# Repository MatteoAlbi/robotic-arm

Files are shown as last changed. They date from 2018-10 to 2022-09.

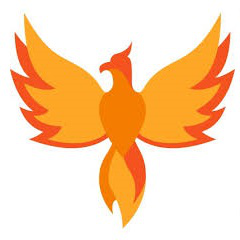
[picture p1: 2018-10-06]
LAST VERSIONS/python, drawing/images/phoenix.jpg

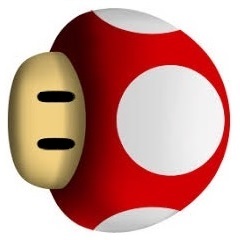
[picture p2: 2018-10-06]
LAST VERSIONS/python, drawing/images/mushroom.jpg

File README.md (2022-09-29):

# robotic-arm
Project developed for the high school graduation final exam.
It's a robotic arm capable to draw simple images or move objects with a claw.

## Description
The robotic arm has been build with ordinary servo-motors and joints designed by myself using SolidWorks and created via 3D-printing (files [here](/solid%20works%20arm%20design)).  
It has two different working configurations:
- **Drawing**: the arm is equipped with a slot for a pancil. An image is processed using a python script, controlled commands are sent via serial communication and executed.
- **Claw**: the arm is controlled via radiocontroller (Turnigy TGY-i6 AFHDS) to move in the 3D space and open/close a claw.

## Python folder
- [braccio](/python/braccio.py): generates a txt file containing the coordinates of the points the arm must follow to draw the image.
- [classes](/python/classes.py): contains basic classes to manage points an lines. It's used in [braccio](/python/braccio.py) to create the drawing steps.
- [comunicazioneArduino_1_0](/python/comunicazioneArduino_1_0.py): manages the communications with the Arduino controlling the servomotors. It reads the file generated by [braccio](/python/braccio.py) and sends the correct commands to the robotic arm.
- [disegna](/python/disegna.py): simulates the drawing process of the robotic arm using the `turtle` library. 
- [dfs](/python/dfs_1_1.py): generates a txt file like [braccio](/python/braccio.py), but implementing a DPS graph visit to compute the drawing steps ([previous version](/python/dfs.py)).
- Code testing: [proveCV_test](/python/proveCV_test.py), [testComunicazioneArduino](/python/testComunicazioneArduino.py), [testBraccio](/python/testBraccio.py).
- Test files: `1.jpg`, `lines.txt`, `prova.jpg`, `prova.txt`.

## Arduino folder
Containing different scripts, e.g. reading the receiver linked to the radiocontroller (e.g. `RX_PCI_MUX`), controlling the robotic arm via python script (`braccio_automatico`), using the calw config. (`braccio_pinza`, `braccio_radiocomandato`), testing scripts used in the development (e.g. `test_pwm_2`, `controllo_vel_motori`, `test_comunicazione_python`).

## LAST VERSIONS folder
Contains the working scripts for each application:
- [arduino, claw](/LAST%20VERSIONS/arduino%2C%20claw): arduino script to control the robotic arm in claw configuration.
- [arduino, drawing](/LAST%20VERSIONS/arduino%2C%20drawing): arduino script that reads and executes commands received on serial port.
- [python, drawing](/LAST%20VERSIONS/python%2C%20drawing): it's devided in two main scripts:
  - [image_analysis](/LAST%20VERSIONS/python%2C%20drawing/image_analysis.py): generates a txt file containing the coordinates of the points the arm must follow to draw the image.  Images examples are saved in the folder [images](/LAST%20VERSIONS/python%2C%20drawing/images) and the image to be analysed is specified in the [config file](/LAST%20VERSIONS/python%2C%20drawing/config.txt). The generated file is saved as `path.txt`.
  - [Arduino_communication](/LAST%20VERSIONS/python%2C%20drawing/Arduino_communication.py): generates and sends the commands to the robotic arm via serial port based on the text file `path.txt`.

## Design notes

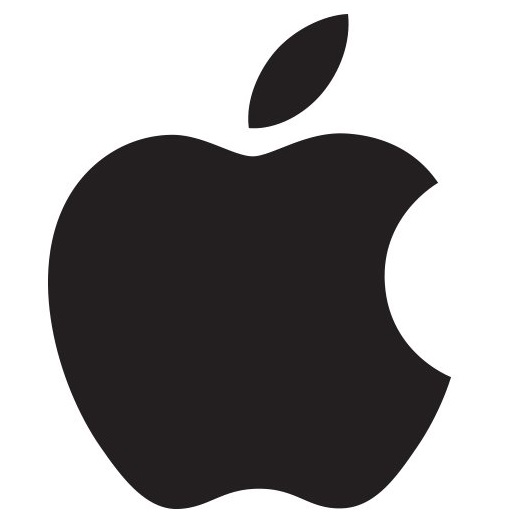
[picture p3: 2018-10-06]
LAST VERSIONS/python, drawing/images/apple.jpg

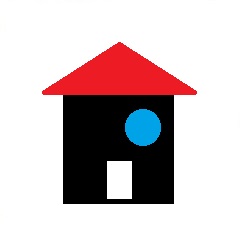
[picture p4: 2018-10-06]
LAST VERSIONS/python, drawing/images/house.jpg

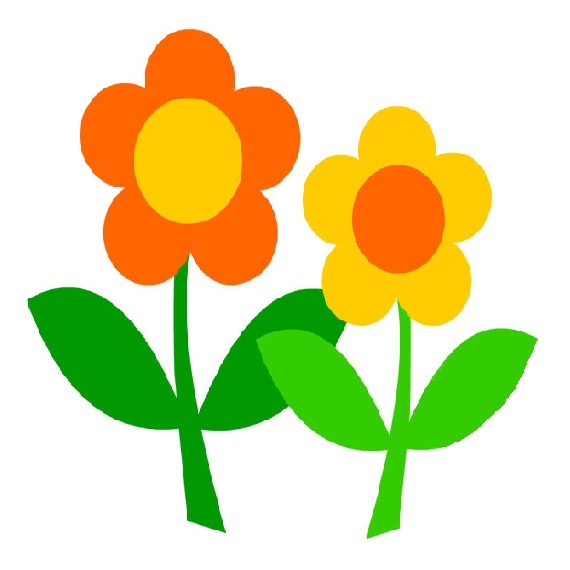
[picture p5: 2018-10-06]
LAST VERSIONS/python, drawing/images/fiore.jpg

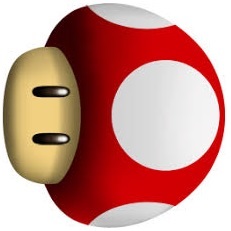
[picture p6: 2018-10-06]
python/prova.jpg

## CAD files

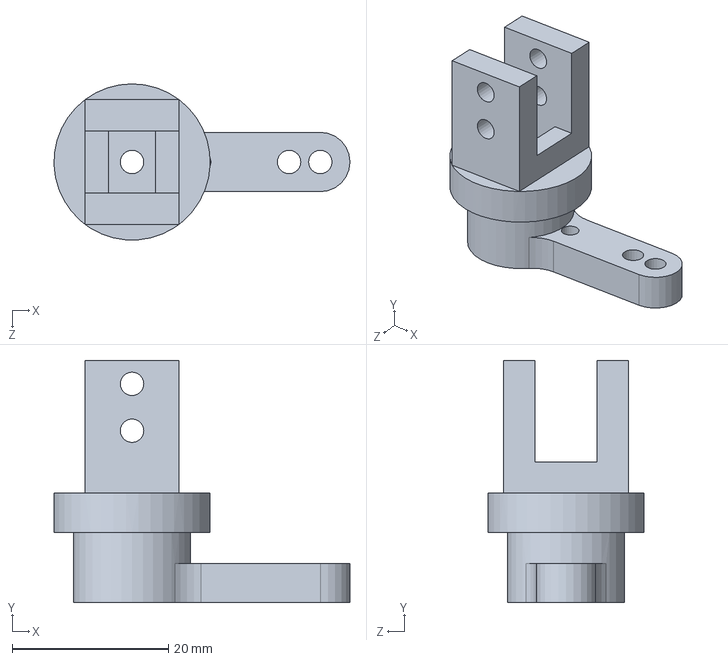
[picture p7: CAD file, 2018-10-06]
solid works arm design/trasmissione verticale.SLDPRT
37.9 x 31.0 x 20.0 mm

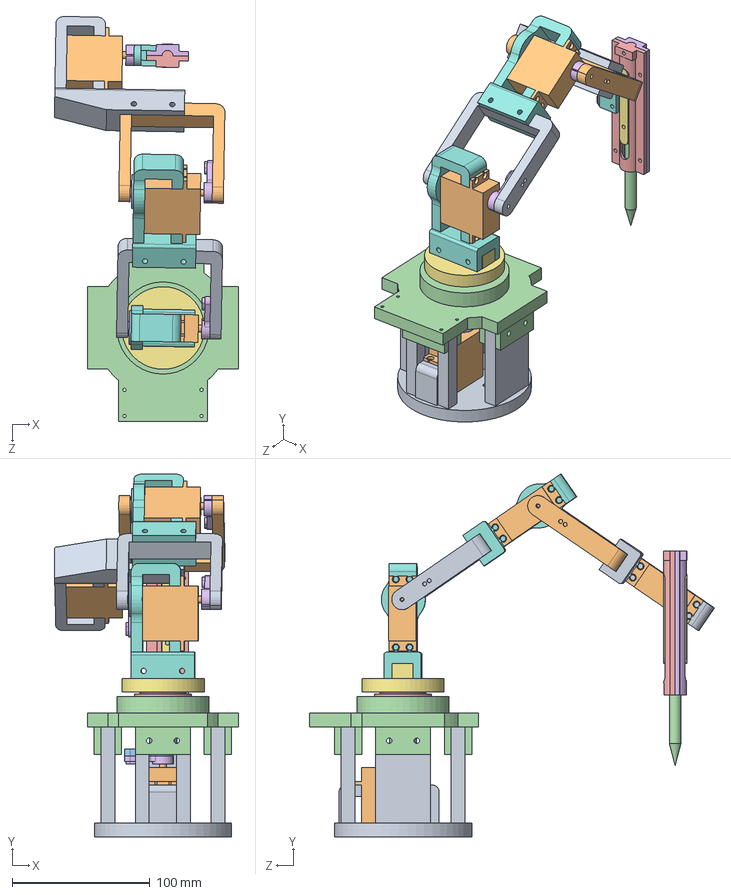
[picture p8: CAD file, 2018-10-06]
solid works arm design/braccio robotico.SLDASM
133.9 x 263.9 x 294.5 mm
base sotto
motore x 4
trasmissione verticale
base sopra
cuscinetto a rulli conici
braccio motore x 4
base motore
attacco x 2
parte rotante
parte rotante penna
cuscinetto a sfera x 2
penna
penna esterno dx
penna esterno sx
penna interno
aggancio penna
attacco penna

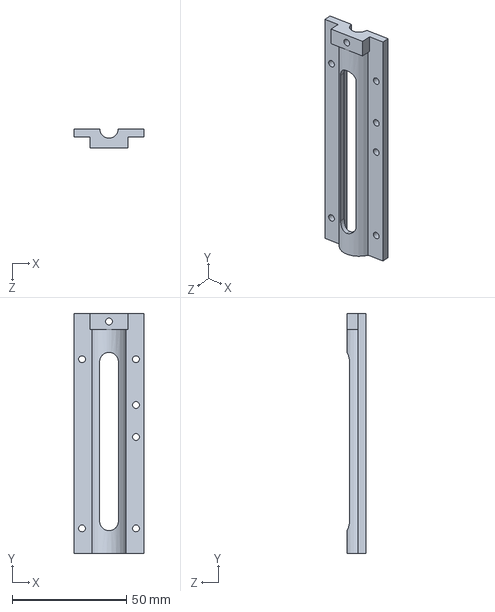
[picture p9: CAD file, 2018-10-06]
solid works arm design/penna esterno sx.SLDPRT
30.6 x 105.0 x 8.30 mm

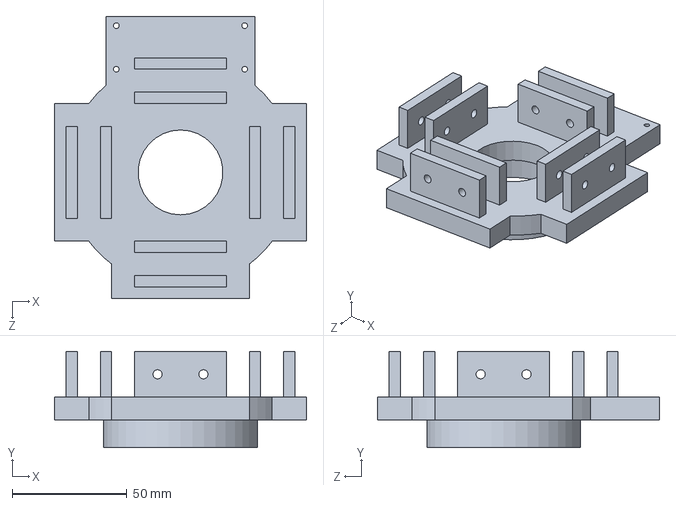
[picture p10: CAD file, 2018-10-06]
solid works arm design/base sopra.SLDPRT
110.0 x 42.0 x 123.0 mm

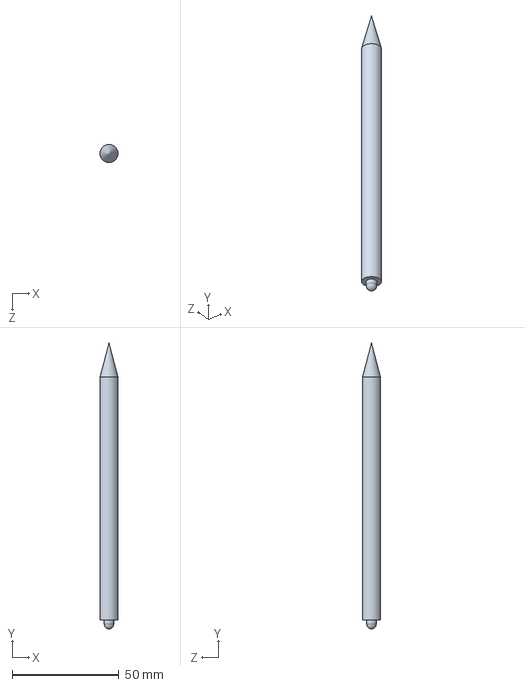
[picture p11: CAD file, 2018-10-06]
solid works arm design/penna.SLDPRT
8.50 x 134.2 x 8.50 mm

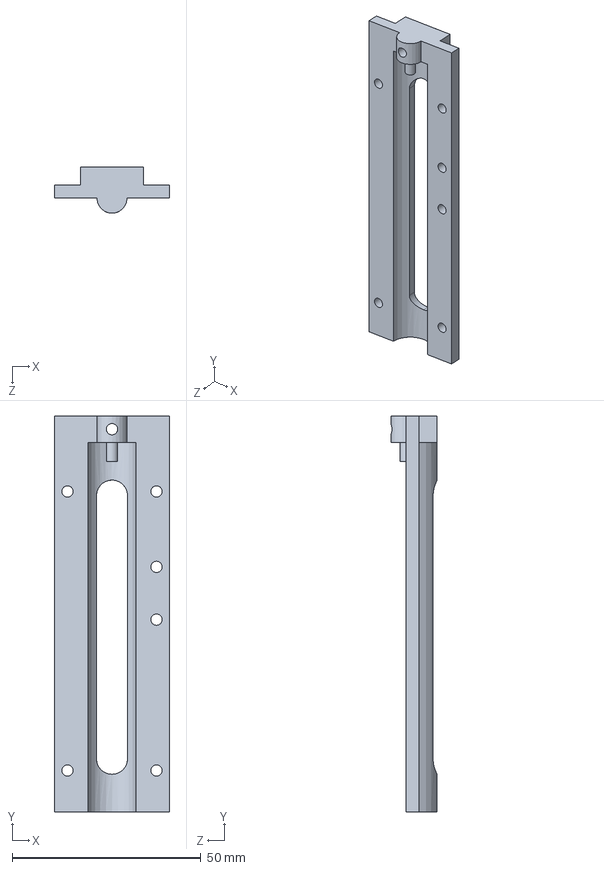
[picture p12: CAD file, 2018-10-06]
solid works arm design/penna esterno dx.SLDPRT
30.6 x 105.0 x 12.3 mm

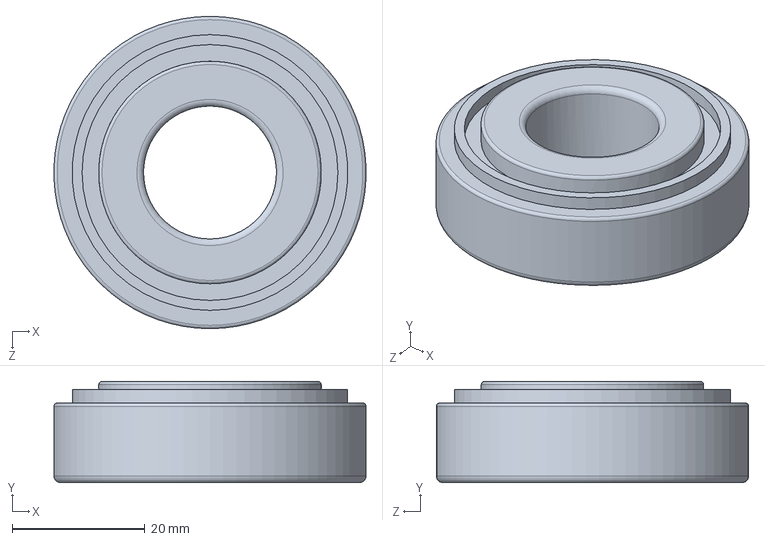
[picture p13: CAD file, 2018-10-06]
solid works arm design/cuscinetto a rulli conici.SLDPRT
47.0 x 15.2 x 47.0 mm

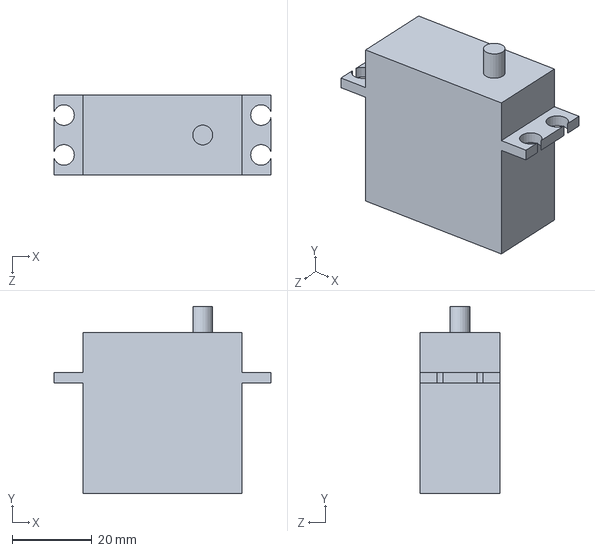
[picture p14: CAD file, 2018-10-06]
solid works arm design/motore.SLDPRT
54.5 x 47.0 x 20.0 mm

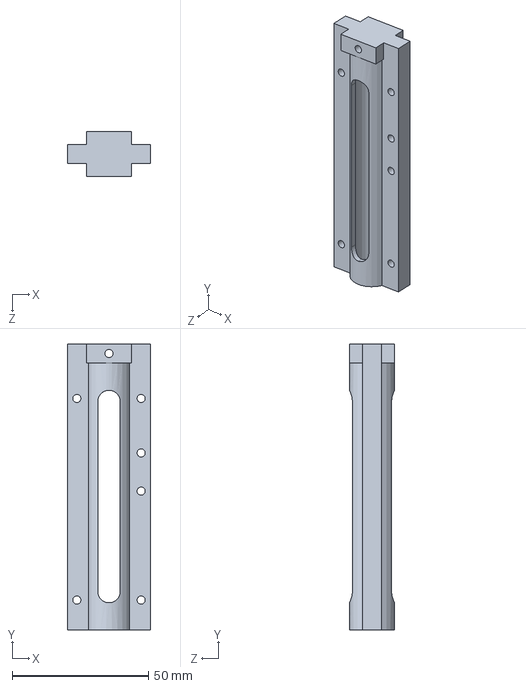
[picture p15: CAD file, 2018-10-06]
solid works arm design/penna esterno.SLDPRT
30.6 x 105.0 x 16.6 mm

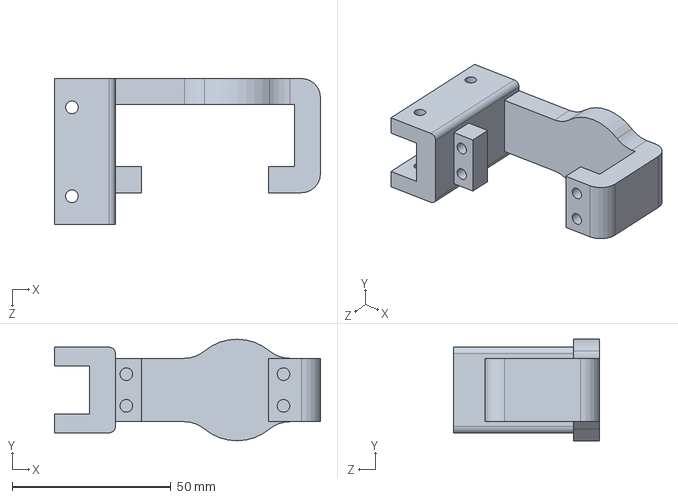
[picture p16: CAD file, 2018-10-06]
solid works arm design/attacco.SLDPRT
83.8 x 32.0 x 46.0 mm

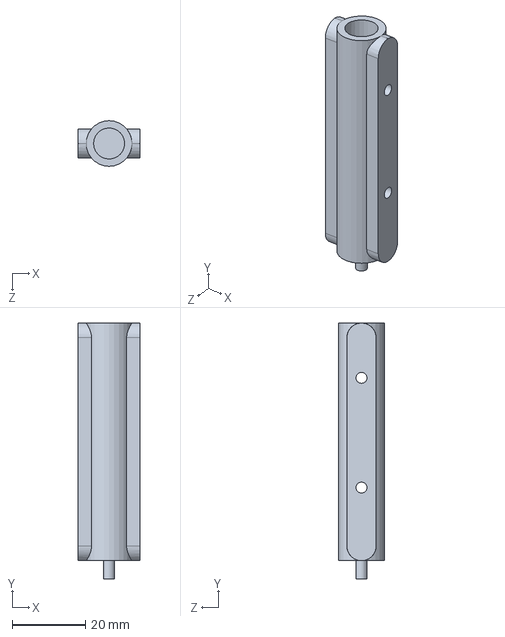
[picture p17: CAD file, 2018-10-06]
solid works arm design/penna interno.SLDPRT
17.0 x 70.0 x 12.5 mm

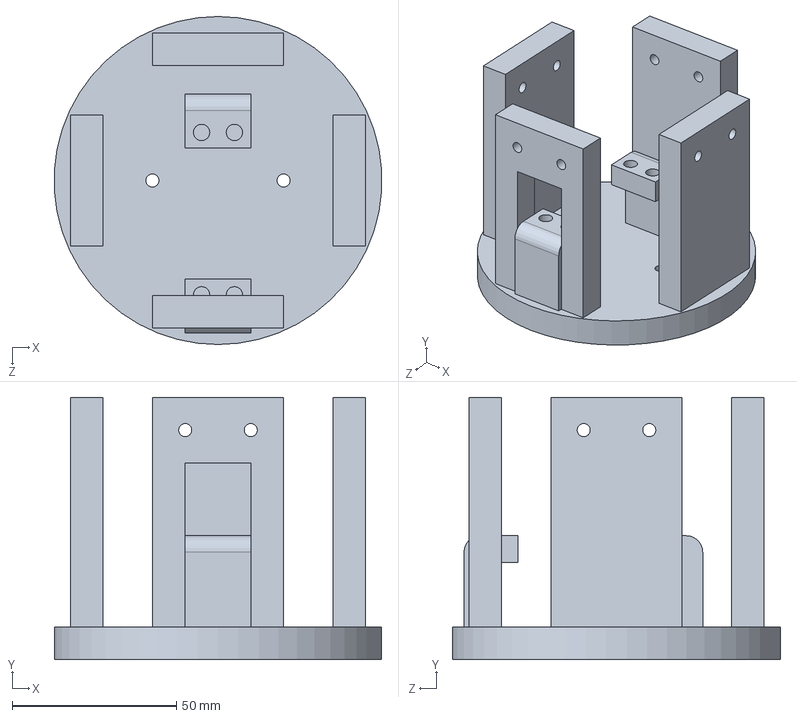
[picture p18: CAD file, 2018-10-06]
solid works arm design/base sotto.SLDPRT
99.8 x 80.0 x 100.0 mm

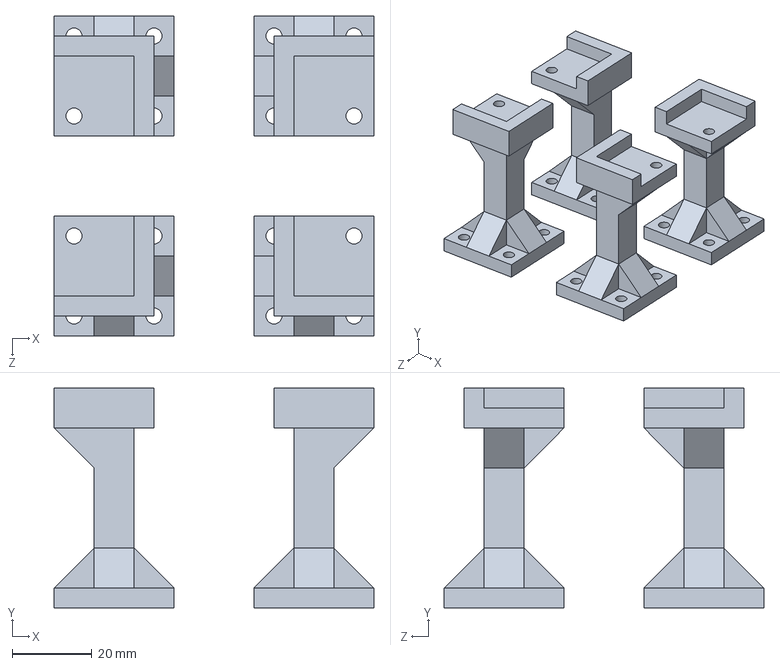
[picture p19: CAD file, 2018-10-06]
solid works arm design/colonne foglio.SLDPRT
80.0 x 55.0 x 80.0 mm

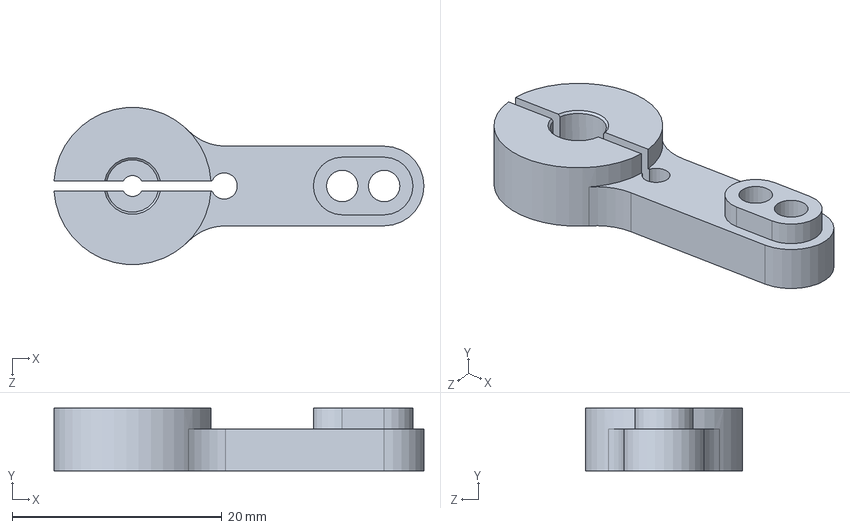
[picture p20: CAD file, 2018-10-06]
solid works arm design/braccio motore.SLDPRT
35.3 x 6.00 x 15.0 mm

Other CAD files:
solid works arm design/cuscinetto a sfera.SLDPRT
solid works arm design/pinza motore.SLDPRT
solid works arm design/aggancio penna.SLDPRT
solid works arm design/parte rotante.SLDPRT
solid works arm design/attacco penna.SLDPRT
solid works arm design/attacco pinza.SLDPRT
solid works arm design/base motore.SLDPRT
solid works arm design/parte rotante penna.SLDPRT
solid works arm design/pinza.SLDPRT

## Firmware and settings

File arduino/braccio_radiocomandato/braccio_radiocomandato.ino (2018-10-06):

//1900071012001800
//3120314531303050
//--IMPORT
#include <math.h>
#include <Wire.h>
#include <Adafruit_PWMServoDriver.h>
#include <avr/interrupt.h>

#define Map(n,a,b,x,y) ((n-a)*(y-x)/(b-a)+x)


//--VARIABILI GENERALI
typedef int Matrix[3][3];
bool boolDebug = false;

//variabili gestione radiocomando
volatile int index = 0;
volatile unsigned long prevTime = 0;
const float velCommands = 1;
const float rangeCoordinates[3][2] = {{-100,100},
                                      {0,200},
                                      {-100,100}};
volatile Matrix commands = {{1500, 1500, 1500},
                            {1500, 1500, 1500},
                            {1500, 1500, 1500}};
volatile bool rising;
float fCommands[3] = {0, 0, 0};
float coeff[3] = {0.4, 0.3, 0.3};
int RXPin[3] = {9,10,11};

//variabili gestione motori
Adafruit_PWMServoDriver pwm = Adafruit_PWMServoDriver();

const int trig = 4, echo = 3;//PIN sensore di prossimità
const float minD = 10.3;//valori sensore di prossimità x distanza pendown[cm]
const float downCoordinates = 0.25, upCoordinates = 30.0;//[mm]
const float mSecPerDeg = 2.666666667;//velocità motore in [deg/msec]

bool penUp = true;
float cycles;//cicli di variazione della pwm
float coordinates[3] = {60,0,downCoordinates}; //coordinate end effector xyz
float angleTarget[4],//[rad], angolo che devono avere motori
      motor[4],//[pwm], pwm attuale motori
      target[4],//[pwm], pwm da raggiungere x arrivare ad angolTarget
      gapPerCycle[4],// [pwm/cycle],variazione bit per ciclo,
      speedMotors[4];//[pwm/rad]rapporto pwm/gradi in base a motore

const int pwmMotors[4][3] = {570, 1810, 3080,//valori pwm per ogni motore per angoli 0,90,180
                             730, 1930, 3100,
                             630, 1860, 3080,
                             400, 1550, 2830};
const int defaultMotors[4] = {pwmMotors[0][1],pwmMotors[1][1],pwmMotors[2][2], pwmMotors[3][2]};//posizione default dei motori
const float angleMotors[4][2] = {{-M_PI_2,  M_PI_2},//range degli angoli dei motori, riferiti alla cinematica del braccio, in [rad]
                                 {0,        M_PI},
                                 {-M_PI,    0},
                                 {-M_PI,    0}};



//--FUNZIONI                      
void coordinatesTooPwmFunc(){//date le coordinate xyz dell'end effector, trova il valore pwm che devono avere i motori
  angleTarget[0] = atan2(coordinates[1],coordinates[0]);//Alfa
  float Beta_st = atan2(coordinates[2], sqrt(sq(coordinates[0])+sq(coordinates[1])));
  float Beta_nd = acos(sqrt(sq(coordinates[0])+sq(coordinates[1])+sq(coordinates[2]))/240);//[mm]
  angleTarget[1] = Beta_st + Beta_nd;//Beta
  angleTarget[2] = Beta_nd*(-2);//Gamma
  angleTarget[3] = - M_PI_2 - angleTarget[1] - angleTarget[2];//Delta

  for(int i=0;i<4;i++){
    target[i] = Map(angleTarget[i], angleMotors[i][0], angleMotors[i][1], pwmMotors[i][0], pwmMotors[i][2]);
  }
}

float cyclesFunc(){//cicli = media degli angoli da percorrere in pwm
  float somma = 0;
  for(int i=0;i<4;i++) somma+=abs(target[i]-motor[i]);
  return somma/4.0*5.0;
}

float tDelayFunc(){//delay tra ogni ciclo = sec per percorrere variazione movimento maggiore
  float vel, maxGapPerCycle = max(abs(gapPerCycle[0]),max(abs(gapPerCycle[1]), max(abs(gapPerCycle[2]), abs(gapPerCycle[3]))));

  for(int i=0;i<4;i++) if(maxGapPerCycle == abs(gapPerCycle[i])) vel = speedMotors[i];
  return maxGapPerCycle*mSecPerDeg/vel;
}

float checkDistance(){//calcola distanza con sensore di prossimità
  float duration, distance, z;
  digitalWrite(trig, HIGH);
  delayMicroseconds(10); 
  digitalWrite(trig, LOW);
  duration = pulseIn(echo, HIGH);
  distance = (duration/2.0) / 29.1;
  if (distance >= 200 || distance <= 0) distance = 9999;
  
//  if(distance > minD){
//    if(downCoordinates-2 < coordinates[2] && coordinates[2] < downCoordinates+2) z = coordinates[2]-2;
//    else if(coordinates[2]>=downCoordinates+2) z = downCoordinates;
//    else z = downCoordinates-2;
//  }
//  else if(distance < minD-0.5){
//    if(downCoordinates-2 < coordinates[2] && coordinates[2] < downCoordinates+2) z = coordinates[2]+2;
//    else if(coordinates[2]<=downCoordinates-2) z = downCoordinates;
//    else z = downCoordinates+2;
//  }
//  else z = coordinates[2];
//
//  return z;

  if (minD-1<distance&&distance<minD) return coordinates[2];
  if (distance>minD) return coordinates[2]-0.5;
  else return coordinates[2]+0.5;
  
  
}

void checkCoordinates(){//controllo su coordinate per mantenerle nel campo di lavoro del braccio
  float tempCoordinates[3];
  for(int i=0;i<2;i++){
    if(abs(fCommands[i]-1500)>50) tempCoordinates[i] = coordinates[i]+(fCommands[i]/1000-1.5)*velCommands;
    else tempCoordinates[i] = coordinates[i];
  }
  tempCoordinates[2] = coordinates[2];
  
  if(fCommands[2]<1300) penUp = true, tempCoordinates[2] = upCoordinates;
  else if(fCommands[2]>1700) penUp = false, tempCoordinates[2] = downCoordinates;
  if(!penUp) tempCoordinates[2] = checkDistance();
  
  float a = tempCoordinates[0], b = tempCoordinates[1], c = tempCoordinates[2];
  if(a<230 && b<230 && c<230 && sqrt(sq(a)+sq(b)+sq(c))<240){
    for(int i=0;i<3;i++) coordinates[i] = tempCoordinates[i];
  }
    
}

void MOVE(){//date le coordinate da raggiungere e le attuali posizioni dei motori, muove il braccio alle coordinate date 
  coordinatesTooPwmFunc();//setta i valori target[i]
  cycles = cyclesFunc();//calcola cicli come media dei gap
  if(boolDebug) Serial.println("gapPerCycle");
  for(int i=0; i<4; i++){
    gapPerCycle[i] = (target[i] - motor[i])/cycles;//variazione della pwm di ogni motore per ciclo
    if(boolDebug) Serial.println(gapPerCycle[i]);
  }

  int tDelay = tDelayFunc();//delay tra ogni ciclo di movimento
  
  for(int i=0; i<cycles; i++){//per ogni ciclo
    for(int j=0; j<4; j++){//per ogni motore
      motor[j] += gapPerCycle[j];//calcolo il  nuovo valore della pwm del motore
      pwm.setPWM(j, 0, int(motor[j]));//setto la pwm al nuovo valore
    }
    delay(tDelay+1);//+1msec per margine
  }
  //for(int i=0; i<4; i++) Serial.println(motor[i]);
  //Serial.println(200);//valore di conferma avvenuto processo
}


void setup() {
  noInterrupts();
  PCICR = 0b00000001;     // turn on port B
  PCMSK0 = 0b00000010;    // turn on pin PCINT9
  for(index = 0; index < 3; index++){
    pinMode(RXPin[index], INPUT);
  }
  pinMode(trig,OUTPUT);
  pinMode(echo,INPUT);
  digitalWrite(trig, LOW);
  rising = false;
  index = 0;
  
  delay(1000);
  
  Serial.begin(9600);
  if(boolDebug) Serial.println("programma per controllo braccio");
  interrupts();
  pwm.begin();
  pwm.setPWMFreq(333);
  
  for(int i=0;i<4;i++){
    speedMotors[i] = (pwmMotors[i][2]-pwmMotors[i][0])/180.0;//rapporto pwm/deg dei motori
    motor[i] = defaultMotors[i];
    pwm.setPWM(i, 0, motor[i]);//posizionamento motori su posizioni di default
  }
}

void loop() {
  //acquisizione coordinate [mm]
  for(int i = 0; i<3; i++){
    fCommands[i] = 0;
    for(int j = 0; j<3; j++){
      fCommands[i] += commands[j][i]*coeff[j];
    }
    
  }
  checkCoordinates();
  /*
  Serial.println("X: "+String(fCommands[0])
             +"   Y: "+String(fCommands[1])
             +"   Z: "+String(fCommands[2]));
  */
  Serial.println("X: "+String(coordinates[0])
             +"   Y: "+String(coordinates[1])
             +"   Z: "+String(coordinates[2]));
  
  //if(millis()%2000==0) Serial.println(check_distance()),Serial.println(coordinates[2]);
  //delay(2000);
  //movimento braccio
  MOVE();
}

ISR(PCINT0_vect){    // Port B, PCINT8 - PCINT14
  if(digitalRead(RXPin[index])==1){ //RISING
    prevTime = micros();
    rising = true;
  }
  else if(digitalRead(RXPin[index])==0 && rising){ //FALLING
    commands[2][index] = commands[1][index];
    commands[1][index] = commands[0][index];
    commands[0][index] = (micros()-prevTime);
    rising = false;
    index = (index+1)%3;
    PCMSK0 = (0b00000010 << index); 
  }
}

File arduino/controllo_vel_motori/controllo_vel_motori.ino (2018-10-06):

//1900071012001800
//3120314531303050
#include <Wire.h>
#include <Adafruit_PWMServoDriver.h>

// called this way, it uses the default address 0x40
Adafruit_PWMServoDriver pwm = Adafruit_PWMServoDriver();

#define PWMMIN  520
#define PWMMAX  3300//max pwm val per pwm a 12 bit
//#define SERVOMIN  0//deg min
//#define SERVOMAX  180//max angolo del motore

float motor[4], target[4], gapPerCycle[4];//bit attuale pwm, bit da raggiungere, variazione bit per ciclo
const float mSecPerDeg = 2.67, cycles = 100.0; 
boolean boolDebug = false;

int pwmMotori[4][3] = {660, 1900, 3120,
                       710, 1930, 3145,
                       650, 1900, 3130,
                       570, 1800, 3050}; 


float tDelayFunc(){//delay tra ogni ciclo = sec per percorrere variazione movimento maggiore
  float vel, maxGapPerCycle = max(abs(gapPerCycle[0]),max(abs(gapPerCycle[1]), max(abs(gapPerCycle[2]), abs(gapPerCycle[3]))));
  
  if      (maxGapPerCycle == abs(gapPerCycle[0]))   vel = (pwmMotori[0][2]-pwmMotori[0][0])/180.0;
  else if (maxGapPerCycle == abs(gapPerCycle[1]))   vel = (pwmMotori[1][2]-pwmMotori[1][0])/180.0;
  else if (maxGapPerCycle == abs(gapPerCycle[2]))   vel = (pwmMotori[2][2]-pwmMotori[2][0])/180.0;
  else                                              vel = (pwmMotori[3][2]-pwmMotori[3][0])/180.0;

  return maxGapPerCycle*mSecPerDeg/vel;
}

void MOVE(){
  if(boolDebug) Serial.println("gapPerCycle");
  for(int i=0; i<4; i++){
    gapPerCycle[i] = (target[i] - motor[i])/cycles;//variazione della pwm di ogni motore per ciclo  
    if(boolDebug) Serial.println(gapPerCycle[i]);
  }

  int tDelay = tDelayFunc();
  
  for(int i=0; i<cycles; i++){//per ogni ciclo
    for(int j=0; j<4; j++){//per ogni motore
      motor[j] += gapPerCycle[j];//calcolo il  nuovo valore della pwm del motore
      pwm.setPWM(j, 0, int(motor[j]));//setto la pwm al nuovo valore
    }
    delay(tDelay+1);//+1msec per margine
  }
  //for(int i=0; i<4; i++) Serial.println(motor[i]);
  Serial.println(200);
}

void setup() {
  Serial.begin(9600);
  if(boolDebug) Serial.println("programma per controllo velocità motori");
  
  pwm.begin();
  pwm.setPWMFreq(333);

  for(int i=0;i<4;i++){
    pwm.setPWM(i, 0, pwmMotori[i][2]);
    motor[i] = pwmMotori[i][2];
  }
}

void loop() {
  if(Serial.available()>=16){//acquisizione dati(4 numeri a 4 cifre)
    for(int i=0; i<4; i++){
      target[i] = 0; 
      for( int j=0;j<4;j++) target[i] += (Serial.read()-48) * pow(10,3-j);
    }
    if(boolDebug) for(int i=0;i<4;i++) Serial.print(motor[i]), Serial.print("  "), Serial.println(target[i]);
    MOVE();
  }
}
